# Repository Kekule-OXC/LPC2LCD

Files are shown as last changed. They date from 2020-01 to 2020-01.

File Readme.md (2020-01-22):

# LPC2LCD
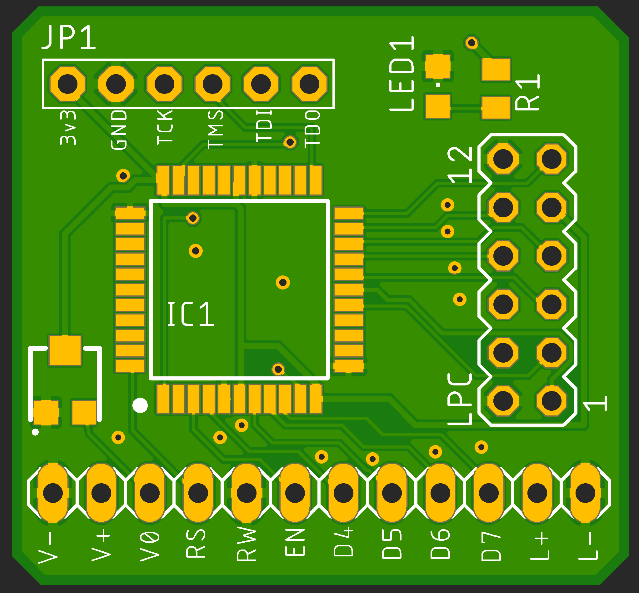
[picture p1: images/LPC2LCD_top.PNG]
top of PCB
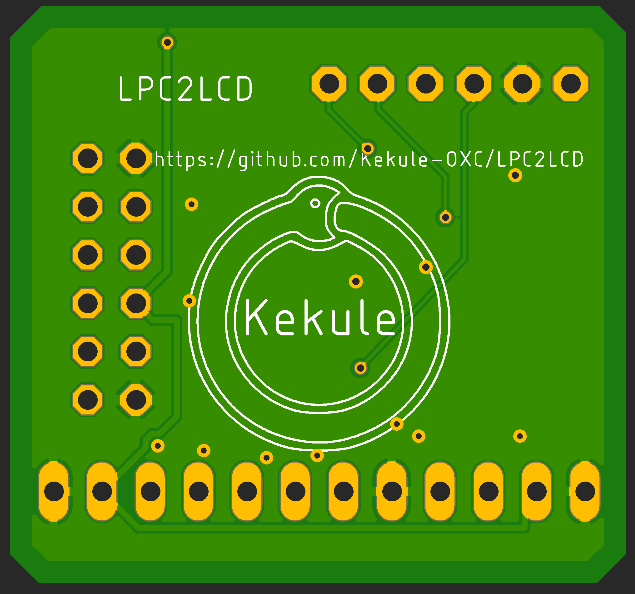
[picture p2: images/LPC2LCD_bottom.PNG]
bottom of PCB


This is a custom board that implements the [AladdinLPC](https://github.com/Ryzee119/AladdinLCD) code written by Ryzee119. Gerbers are available [here](eagle/LPC2LCD_v1_gerbers.zip), and all Eagle design files can be found in the eagle directory

This VHDL was writtenby Ryzee119 to replace the CPLD logic on the cheap AladdinXT 4032 Original Xbox modchip.  The pins have been remapped though to allow a cleaner layout on the PCB.  This is best used with a TSOP flashed console. Soft modded functionality unverified.

The Lattice LC4032V CPLD  is extremely limited, so this is a bare minimum to reduce macro-cell usage to fit onto the CPLD. Therefore it will not support any other functionality.

-   This is **NOT** a modchip.
-   This does not support adjusting the backlight via the dashboard settings.
-   This has no contrast control through the dashboard settings. Use the on board trim pot to set the desired contrast.

# Instructions

1.  Connect a JTAG programmer to the JTAG pins.
    
2.  Make sure to apply 3.3V power to the LPC2PCB board. This can be done by plugging it into the LPC port on the Xbox, an external power supply, or a JTAG programmer that can supply power.  A modified Lattice USB programmer clone or FlashCat are two examples of programmers that can supply power.
    
3.  Program the CPLD with the  `SVF`  file in this repository . It can be programmed with  [UrJTAG](http://urjtag.org/)  using a  [compatible programming cable](http://urjtag.org/book/_system_requirements.html#_supported_jtag_adapters_cables). The general programming sequence in UrJTAG is something like: (Commands written in  **bold**).
    
    **cable usbblaster**  _Type  `help cable`  for other supported cables._  
    **detect**  _To confirm that the cpld is detected._  
    **svf LPC2LCD.SVF progress**  _To program the CPLD._
        
4.  Remove the JTAG programming points.
    
5.  Remove the flash memory and socket from the Aladdin Chip to expose the required usable IO pads. Be careful not too damage the pads.
    
6.  Wire the LCD.
    
7.  Install onto the LPC header in your Xbox. There is no other connections to worry about.  _If you have a 1.6 motherboard you will need to rebuild the LPC as you would for a modchip install.  **Don't**  ground any D0 points etc._
    
8.  Enable  `SmartXX`  LCD in your dashboard.
    
9.  Use the trim pot on the top of the board to set the desired contrast

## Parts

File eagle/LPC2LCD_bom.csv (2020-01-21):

Part | Value | Device | Package | Description | DESCRIPTION | HEIGHT | MANUFACTURER_NAME | MANUFACTURER_PART_NUMBER | MF | MOUSER_PART_NUMBER | MOUSER_PRICE-STOCK | MPN | OC_FARNELL | OC_NEWARK | POPULARITY
IC1 | LC4032V-75TN44C | LC4032V-75TN44C | QFP80P1200X1200X120-44N | LC4032V-75TN44C, CPLD ispMACH 4000V EEPROM 32 Cells, 30 I/O, 36 Labs, 7.5ns, ISP, 3 3.6 V 44-Pin TQFP | LC4032V-75TN44C, CPLD ispMACH 4000V EEPROM 32 Cells, 30 I/O, 36 Labs, 7.5ns, ISP, 3 3.6 V 44-Pin TQFP | 1.2mm | Lattice Semiconductor | LC4032V-75TN44C |  | 842-LC4032V75TN44C | https://www.mouser.com/Search/Refine.aspx?Keyword=842-LC4032V75TN44C
JP1 |  | PINHD-1X6B | 1X06-BIG | PIN HEADER
JP2 |  | PINHD-1X12 | 1X12 | PIN HEADER
LED1 |  | LEDCHIPLED_0805 | CHIPLED_0805 | LED
LPC |  | MA06-2 | MA06-2 | PIN HEADER |  |  |  |  |  |  |  |  | unknown | unknown | 8
R1 |  | R-US_R0805 | R0805 | RESISTOR, American symbol
R2 | TC33X-2-302E | TC33X-2-302E | TC33X-2 | Trimmer Resistors - SMD 3MM 3KOHMS 25% 0.1WATT OPEN FRM | Trimmer Resistors - SMD 3MM 3KOHMS 25% 0.1WATT OPEN FRM | mm | Bourns | TC33X-2-302E |  | 652-TC33X-2-302E | https://www.mouser.com/Search/Refine.aspx?Keyword=652-TC33X-2-302E

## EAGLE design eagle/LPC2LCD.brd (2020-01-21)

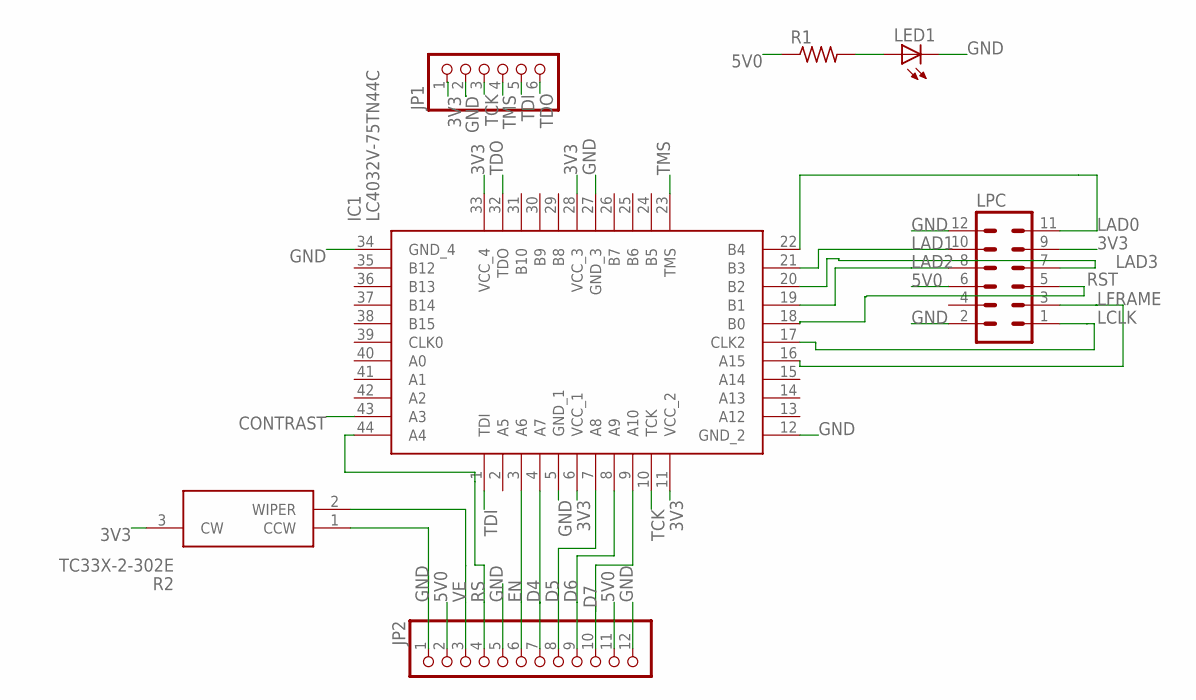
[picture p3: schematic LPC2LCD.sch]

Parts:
IC1: LC4032V-75TN44C; QFP80P1200X1200X120-44N
JP1: PINHD-1X6B; 1X06-BIG
JP2: PINHD-1X12; 1X12
LED1: LEDCHIPLED_0805; CHIPLED_0805
LPC: MA06-2
R1: R-US_R0805; R0805
R2: TC33X-2-302E; TC33X-2

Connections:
3V3: IC1.6 (VCC_1), IC1.11 (VCC_2), IC1.28 (VCC_3), IC1.33 (VCC_4), JP1.1, LPC.9, R2.3 (CW)
5V0: JP2.2, JP2.11, LPC.6, R1.1
CONTRAST: IC1.43 (A3)
D4: IC1.4 (A7), JP2.7
D5: IC1.7 (A8), JP2.8
D6: IC1.8 (A9), JP2.9
D7: IC1.9 (A10), JP2.10
EN: IC1.3 (A6), JP2.6
GND: IC1.5 (GND_1), IC1.12 (GND_2), IC1.27 (GND_3), IC1.34 (GND_4), JP1.2, JP2.1, JP2.5, JP2.12, LED1.C, LPC.2, LPC.12, R2.1 (CCW)
LAD0: IC1.22 (B4), LPC.11
LAD1: IC1.21 (B3), LPC.10
LAD2: IC1.19 (B1), LPC.8
LAD3: IC1.20 (B2), LPC.7
LCLK: IC1.17 (CLK2), LPC.1
LFRAME: IC1.16 (A15), LPC.3
unnamed: LED1.A, R1.2
RS: IC1.44 (A4), JP2.4
RST: IC1.18 (B0), LPC.5
TCK: IC1.10 (TCK), JP1.3
TDI: IC1.1 (TDI), JP1.5
TDO: IC1.32 (TDO), JP1.6
TMS: IC1.23 (TMS), JP1.4
VE: JP2.3, R2.2 (WIPER)

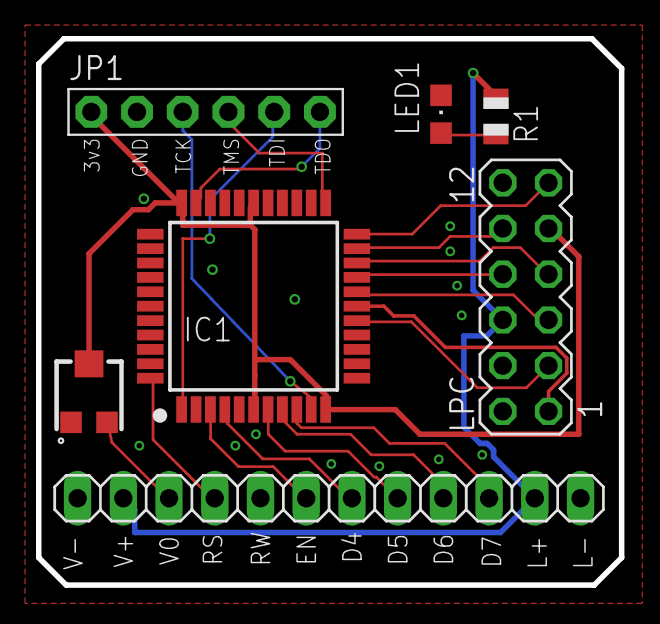
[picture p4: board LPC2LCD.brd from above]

Board: 2 copper layers, 32.4 x 30.4 mm, 8 parts (1 on the bottom side), 22 nets.

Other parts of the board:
U$1: KEKULE-0002
